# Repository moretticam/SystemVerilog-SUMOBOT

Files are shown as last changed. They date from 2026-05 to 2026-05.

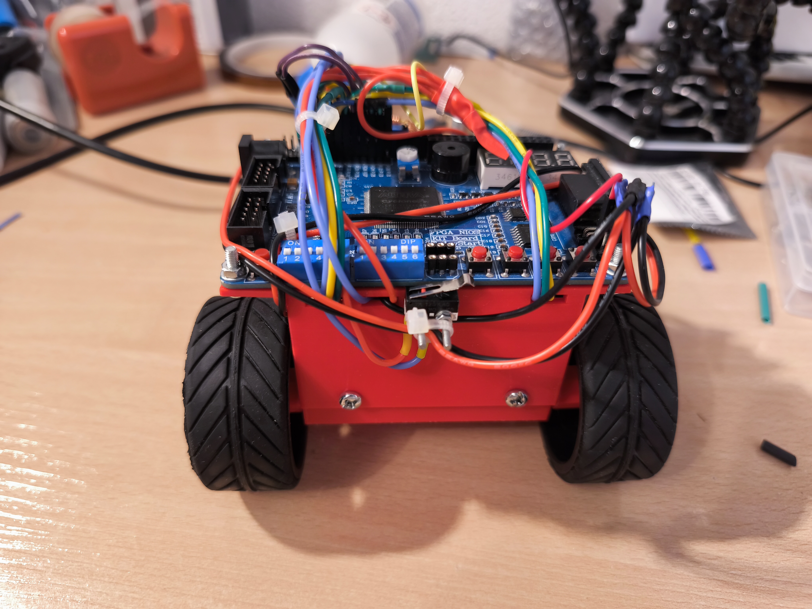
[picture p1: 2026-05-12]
Sumo_Robot_Media/IMG_20260503_175136.jpg

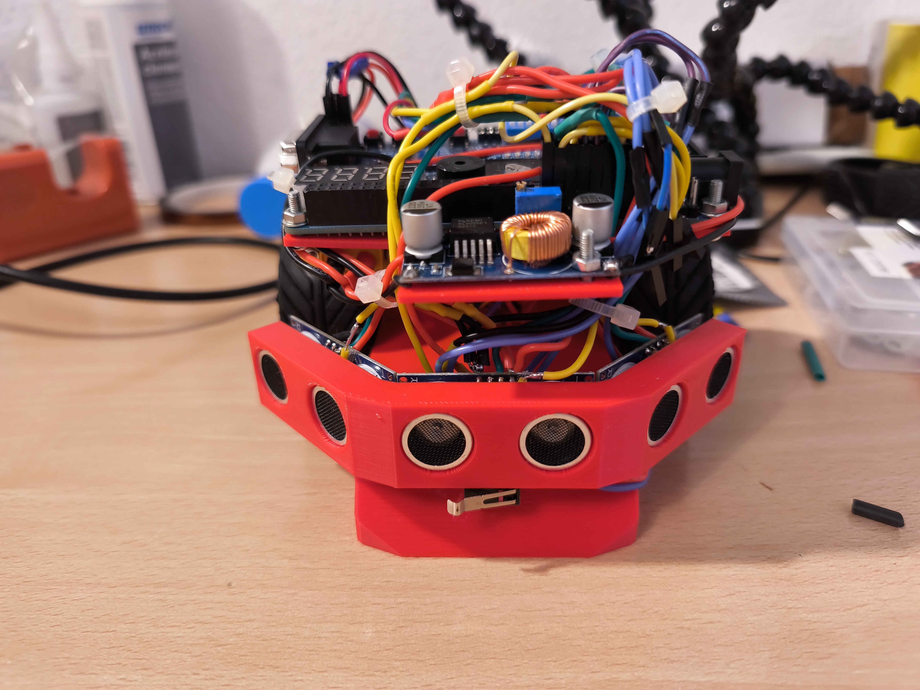
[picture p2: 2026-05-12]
Sumo_Robot_Media/IMG_20260503_175129.jpg

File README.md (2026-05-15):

# SystemVerilog-SUMOBOT
SystemVerilog code for our autonomus SUMO BOT. Participated and WON! :) the **2026 AESSBOT tournament at UPC (Universitat Politècnica de Catalunya)**. It was the only HDL-based design out of 16 participants.
This repository contains the RTL design that runs on the robot's FPGA, a legacy Cyclone I dev board. It includes sensor interfacing, motor control, and the high-level behavior FSM that decides when to charge, evade, or search for an opponent.

---
## Hardware 

| Component | Part |
|---|---|
| FPGA board | Altera Cyclone I EP1C3T144C8N dev-board|
| Distance sensors | 3x HC-SR04 ultrasound sensors|
| Motor driver | TB6612FNG |
| Chassis | 3D-Designs-for-the-robot.3mf |
---

## Functionalities
- Control of two DC motors
  - in-FPGA fabric PWM signal generation
- Sequential reading of 3 ultrasound sensors
- Automatic selection of closest opponent
- Prioritized PANIC sequence when ring edge is detected
- On-board debug LEDs
- Integrated button debouncer & sequencer
- *boxes* mode: will make you look very cool when changing tires!

## NOTE
We are working on a proper README, as well as adding further explanations. Feel free to check out the already commented bits.

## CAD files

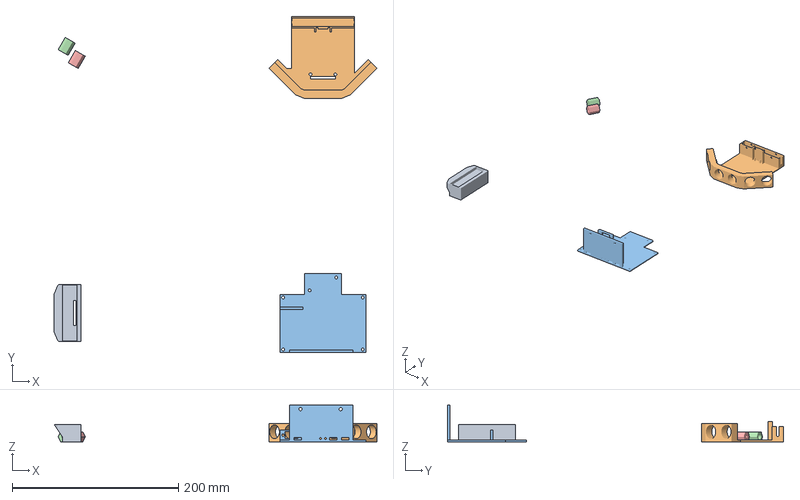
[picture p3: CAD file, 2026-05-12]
3D-Designs-for-the-robot.3mf
388.2 x 404.0 x 44.0 mm
Cuerpo5.obj
Cuerpo2.obj
Cuerpo8.obj
Cuerpo3.obj
Cuerpo1.obj

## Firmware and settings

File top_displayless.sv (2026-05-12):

/*
	Integrated top without display
*/

module top_displayless #(
    parameter int F_CLK_HZ  = 50_000_000,
    parameter int PRECISION = 10,

    parameter bit BUTTON_ACTIVE_LOW = 1'b1,
    parameter bit LINE_ACTIVE_HIGH  = 1'b1,

    parameter int DETECT_DISTANCE_MM = 500,

    parameter logic [PRECISION-1:0] SEARCH_SPEED   = 10'd350,
    parameter logic [PRECISION-1:0] APPROACH_SPEED = 10'd600,
    parameter logic [PRECISION-1:0] ATTACK_SPEED   = 10'd850,
    parameter logic [PRECISION-1:0] TURN_SPEED     = 10'd600,
    parameter logic [PRECISION-1:0] BACK_SPEED     = 10'd650,

    // "Boxes" speed when screwing/unscrewin tires
    parameter logic [PRECISION-1:0] BOX_SPEED      = 10'd450,

    // Last-minute add-on: delay after START button is pressed before starting FSM
    parameter int START_DELAY_MS = 5000,

    parameter int ATTACK_NEAR_DISTANCE_MM = 250,

    parameter int DEADTIME_MS   = 120,
    parameter int BACKWARD_MS   = 450,
    parameter int ROTATE_180_MS = 500,
    parameter int TILT_45_MS    = 140,

    parameter bit RIGHT_INVERT = 1'b0,
    parameter bit LEFT_INVERT  = 1'b0
)(
    input  logic        rst_n,
    input  logic        clk,

    //Ultrasounds	
    output logic        ultrasoindos_T1,
    input  logic        uttrasonidos_R1,
    output logic        ultrasoindos_T2,
    input  logic        uttrasonidos_R2,
    output logic        ultrasoindos_T3,
    input  logic        uttrasonidos_R3,

    // Line sensors
    input  logic [3:0]  sensores_final_linea,
    output logic        Activate_sensor_final_de_linea,

    // TB6612 driver
    output logic [2:0]  motor_derecha,
    output logic [2:0]  motor_izquierda,
    output logic        stby_motores,

    /* Buttons
			boton_start_driver -> K3: start FSM + enable driver
			boton_box_tighten  -> K1: boxes screw while pressed
			boton_box_loosen   -> K2: boxes unscrew while pressed
	 */
    input  logic        boton_start_driver,
    input  logic        boton_box_tighten,
    input  logic        boton_box_loosen,

    // Unused display
    output logic        dp_out,
    output logic [3:0]  disp_sel,
    output logic [6:0]  segment_val,

    output logic        bell,

    // Optional debug LEDs
    output logic [2:0]  debug_fsm_state,
    output logic [2:0]  debug_cmd,
    output logic [2:0]  debug_cmd_applied,
    output logic [2:0]  debug_detect,
    output logic        debug_motor_enable,
    output logic        debug_line,
    output logic        debug_deadtime,
    output logic        debug_brake
);

    logic start_pulse;
    logic box_tighten_pressed;
    logic box_loosen_pressed;
    logic motor_enable;
    logic start_delay_active;
    logic start_delayed_pulse;

	 /*
		Last-minute add-on: Robust delay, counts ms instead of cycles.
		DIDN'T WORK, REVIEW
	*/
    localparam int CLK_PER_MS = (F_CLK_HZ + 999) / 1000;
    localparam int START_DELAY_MS_SAFE = (START_DELAY_MS <= 0) ? 1 : START_DELAY_MS;
    localparam int CLK_MS_W = (CLK_PER_MS <= 1) ? 1 : $clog2(CLK_PER_MS);
    localparam int DELAY_MS_W = (START_DELAY_MS_SAFE <= 1) ? 1 : $clog2(START_DELAY_MS_SAFE + 1);

    logic [CLK_MS_W-1:0] delay_clk_cnt;
    logic [DELAY_MS_W-1:0] delay_ms_cnt;

    logic box_mode;
    logic [2:0] cmd_to_driver;
    logic [PRECISION-1:0] speed_to_driver;
    logic driver_enable;

    logic line_detected;

    logic us_left;
    logic us_center;
    logic us_right;

    logic [11:0] distance_left;
    logic [11:0] distance_center;
    logic [11:0] distance_right;

    logic [2:0] cmd;
    logic [PRECISION-1:0] speed;

    assign bell = 1'b1;
    assign Activate_sensor_final_de_linea = 1'b1;

    assign line_detected = LINE_ACTIVE_HIGH ? (|sensores_final_linea) : (~&sensores_final_linea);

    assign debug_cmd          = cmd;
    assign debug_detect       = {us_left, us_center, us_right};
    assign debug_motor_enable = driver_enable;
    assign debug_line         = line_detected;

    button #(
        .F_CLK_HZ(F_CLK_HZ),
        .DEBOUNCE_MS(30),
        .ACTIVE_LOW(BUTTON_ACTIVE_LOW)
    ) start_button_i (
        .clk(clk),
        .rst_n(rst_n),
        .btn_in(boton_start_driver),
        .btn_pressed(),
        .btn_pulse(start_pulse)
    );

    button #(
        .F_CLK_HZ(F_CLK_HZ),
        .DEBOUNCE_MS(30),
        .ACTIVE_LOW(BUTTON_ACTIVE_LOW)
    ) box_tighten_button_i (
        .clk(clk),
        .rst_n(rst_n),
        .btn_in(boton_box_tighten),
        .btn_pressed(box_tighten_pressed),
        .btn_pulse()
    );

    button #(
        .F_CLK_HZ(F_CLK_HZ),
        .DEBOUNCE_MS(30),
        .ACTIVE_LOW(BUTTON_ACTIVE_LOW)
    ) box_loosen_button_i (
        .clk(clk),
        .rst_n(rst_n),
        .btn_in(boton_box_loosen),
        .btn_pressed(box_loosen_pressed),
        .btn_pulse()
    );
	
	 /*
		FAULTY -> REVIEW NEEDED
		
		K3 starts START_DELAY_MS delay
	 */
    always_ff @(posedge clk or negedge rst_n) begin
        if (!rst_n) begin
            motor_enable        <= 1'b0;
            start_delay_active  <= 1'b0;
            delay_clk_cnt       <= '0;
            delay_ms_cnt        <= '0;
            start_delayed_pulse <= 1'b0;
        end else begin
            start_delayed_pulse <= 1'b0;

            if (start_pulse && !motor_enable && !start_delay_active) begin
                start_delay_active <= 1'b1;
                delay_clk_cnt      <= '0;
                delay_ms_cnt       <= '0;
            end else if (start_delay_active) begin
                if (delay_clk_cnt == CLK_PER_MS - 1) begin
                    delay_clk_cnt <= '0;

                    if (delay_ms_cnt == START_DELAY_MS_SAFE - 1) begin
                        start_delay_active  <= 1'b0;
                        delay_ms_cnt        <= '0;
                        motor_enable        <= 1'b1;
                        start_delayed_pulse <= 1'b1;
                    end else begin
                        delay_ms_cnt <= delay_ms_cnt + 1'b1;
                    end
                end else begin
                    delay_clk_cnt <= delay_clk_cnt + 1'b1;
                end
            end
        end
    end

    assign box_mode = box_tighten_pressed ^ box_loosen_pressed;

    always_comb begin
        cmd_to_driver   = cmd;
        speed_to_driver = speed;
        driver_enable   = motor_enable;

        if (box_mode) begin
            driver_enable   = 1'b1;
            speed_to_driver = BOX_SPEED;
            if (box_tighten_pressed) begin
                cmd_to_driver = 3'd2; // CMD_FORWARD
            end else begin
                cmd_to_driver = 3'd3; // CMD_BACKWARD
            end
        end
    end
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

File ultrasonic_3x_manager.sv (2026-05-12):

module ultrasonic_3x_manager #(
    parameter int F_CLK_HZ               = 50_000_000,
    parameter int STARTUP_DELAY_MS       = 100,
    parameter int DELAY_AFTER_MEASURE_MS = 60,
    parameter int SENSOR_TIMEOUT_MS      = 35,
    parameter int DETECT_DISTANCE_MM     = 500,
    parameter int MIN_VALID_DISTANCE_MM  = 20,
    parameter int TIMEOUT_DISTANCE_MM    = 4030
)(
    input  logic        clk,
    input  logic        rst_n,
    input  logic        enable,

    input  logic        echo_left,
    input  logic        echo_center,
    input  logic        echo_right,

    output logic        trig_left,
    output logic        trig_center,
    output logic        trig_right,

    output logic        detect_left,
    output logic        detect_center,
    output logic        detect_right,

    output logic [11:0] distance_left,
    output logic [11:0] distance_center,
    output logic [11:0] distance_right,

    output logic [1:0]  debug_sensor_active,
    output logic        debug_new_sample
);

    localparam int STARTUP_TICKS = (F_CLK_HZ / 1000) * STARTUP_DELAY_MS;
    localparam int DELAY_TICKS   = (F_CLK_HZ / 1000) * DELAY_AFTER_MEASURE_MS;

    localparam int STARTUP_W = (STARTUP_TICKS <= 1) ? 1 : $clog2(STARTUP_TICKS + 1);
    localparam int DELAY_W   = (DELAY_TICKS   <= 1) ? 1 : $clog2(DELAY_TICKS   + 1);

    typedef enum logic [2:0] {
        ST_STARTUP,
        ST_PULSE_LEFT,
        ST_WAIT_LEFT,
        ST_PULSE_CENTER,
        ST_WAIT_CENTER,
        ST_PULSE_RIGHT,
        ST_WAIT_RIGHT,
        ST_DELAY
    } state_t;

    typedef enum logic [1:0] {
        SENSOR_LEFT   = 2'd0,
        SENSOR_CENTER = 2'd1,
        SENSOR_RIGHT  = 2'd2
    } sensor_t;

    state_t  state;
    sensor_t next_sensor;

    logic [STARTUP_W-1:0] startup_cnt;
    logic [DELAY_W-1:0]   delay_cnt;

    logic read_left, read_center, read_right;
    logic new_left, new_center, new_right;

    logic [11:0] raw_distance_left;
    logic [11:0] raw_distance_center;
    logic [11:0] raw_distance_right;

    assign detect_left = enable &&
                         (distance_left >= MIN_VALID_DISTANCE_MM) &&
                         (distance_left <= DETECT_DISTANCE_MM) &&
                         (distance_left <  TIMEOUT_DISTANCE_MM);

    assign detect_center = enable &&
                           (distance_center >= MIN_VALID_DISTANCE_MM) &&
                           (distance_center <= DETECT_DISTANCE_MM) &&
                           (distance_center <  TIMEOUT_DISTANCE_MM);

    assign detect_right = enable &&
                          (distance_right >= MIN_VALID_DISTANCE_MM) &&
                          (distance_right <= DETECT_DISTANCE_MM) &&
                          (distance_right <  TIMEOUT_DISTANCE_MM);

    HC_SR04 #(.clk_freq(F_CLK_HZ), .TIMEOUT_MS(SENSOR_TIMEOUT_MS)) us_left_i (
        .rst_n(rst_n), .clk(clk), .read(read_left), .echo_in(echo_left),
        .trig(trig_left), .distance(raw_distance_left), .new_data(new_left)
    );

    HC_SR04 #(.clk_freq(F_CLK_HZ), .TIMEOUT_MS(SENSOR_TIMEOUT_MS)) us_center_i (
        .rst_n(rst_n), .clk(clk), .read(read_center), .echo_in(echo_center),
        .trig(trig_center), .distance(raw_distance_center), .new_data(new_center)
    );

    HC_SR04 #(.clk_freq(F_CLK_HZ), .TIMEOUT_MS(SENSOR_TIMEOUT_MS)) us_right_i (
        .rst_n(rst_n), .clk(clk), .read(read_right), .echo_in(echo_right),
        .trig(trig_right), .distance(raw_distance_right), .new_data(new_right)
    );

    always_ff @(posedge clk or negedge rst_n) begin
        if (!rst_n) begin
            state               <= ST_STARTUP;
            next_sensor         <= SENSOR_LEFT;
            startup_cnt         <= '0;
            delay_cnt           <= '0;
            read_left           <= 1'b0;
            read_center         <= 1'b0;
            read_right          <= 1'b0;
            distance_left       <= 12'd4030;
            distance_center     <= 12'd4030;
            distance_right      <= 12'd4030;
            debug_sensor_active <= SENSOR_LEFT;
            debug_new_sample    <= 1'b0;
        end else begin
            read_left        <= 1'b0;
            read_center      <= 1'b0;
            read_right       <= 1'b0;
            debug_new_sample <= 1'b0;

            if (!enable) begin
                state       <= ST_STARTUP;
                startup_cnt <= '0;
                delay_cnt   <= '0;
            end else begin
                case (state)
                    ST_STARTUP: begin
                        debug_sensor_active <= SENSOR_LEFT;
                        if (startup_cnt >= STARTUP_TICKS - 1) begin
                            startup_cnt <= '0;
                            state       <= ST_PULSE_LEFT;
                        end else begin
                            startup_cnt <= startup_cnt + 1'b1;
                        end
                    end

                    ST_PULSE_LEFT: begin
                        read_left           <= 1'b1;
                        debug_sensor_active <= SENSOR_LEFT;
                        state               <= ST_WAIT_LEFT;
                    end

                    ST_WAIT_LEFT: begin
                        debug_sensor_active <= SENSOR_LEFT;
                        if (new_left) begin
                            distance_left    <= raw_distance_left;
                            debug_new_sample <= 1'b1;
                            next_sensor      <= SENSOR_CENTER;
                            delay_cnt        <= '0;
                            state            <= ST_DELAY;
                        end
                    end

                    ST_PULSE_CENTER: begin
                        read_center         <= 1'b1;
                        debug_sensor_active <= SENSOR_CENTER;
                        state               <= ST_WAIT_CENTER;
                    end

                    ST_WAIT_CENTER: begin
                        debug_sensor_active <= SENSOR_CENTER;
                        if (new_center) begin
                            distance_center  <= raw_distance_center;
                            debug_new_sample <= 1'b1;
                            next_sensor      <= SENSOR_RIGHT;
                            delay_cnt        <= '0;
                            state            <= ST_DELAY;
                        end
                    end

                    ST_PULSE_RIGHT: begin
                        read_right          <= 1'b1;
                        debug_sensor_active <= SENSOR_RIGHT;
                        state               <= ST_WAIT_RIGHT;
                    end
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
